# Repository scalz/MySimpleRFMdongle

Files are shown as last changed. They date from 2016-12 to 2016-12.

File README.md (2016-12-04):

# MySimpleRFMdongle
This is a 32bit ATSAM USB dongle with radio footprint for RFM69 or Lora Long range RFM95.

My main use is mini Serial Mysensors GW, and sniffer/debug tool with MYSController. etc.
Not a fancy thing, but I use it, and it didn't take lot of space on a panel when i ordered it so, why not :)

Tested with RFM69 and RFM95.
Just plug it, no usb cable!

Revision 1
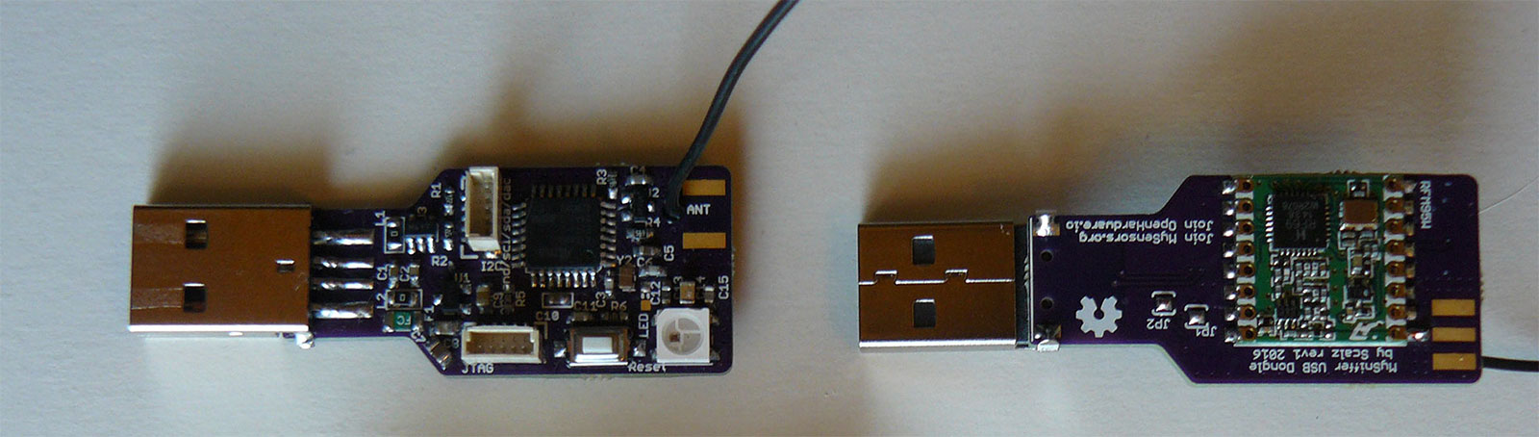
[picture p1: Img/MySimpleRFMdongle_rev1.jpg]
dongle rev1


Revision 2
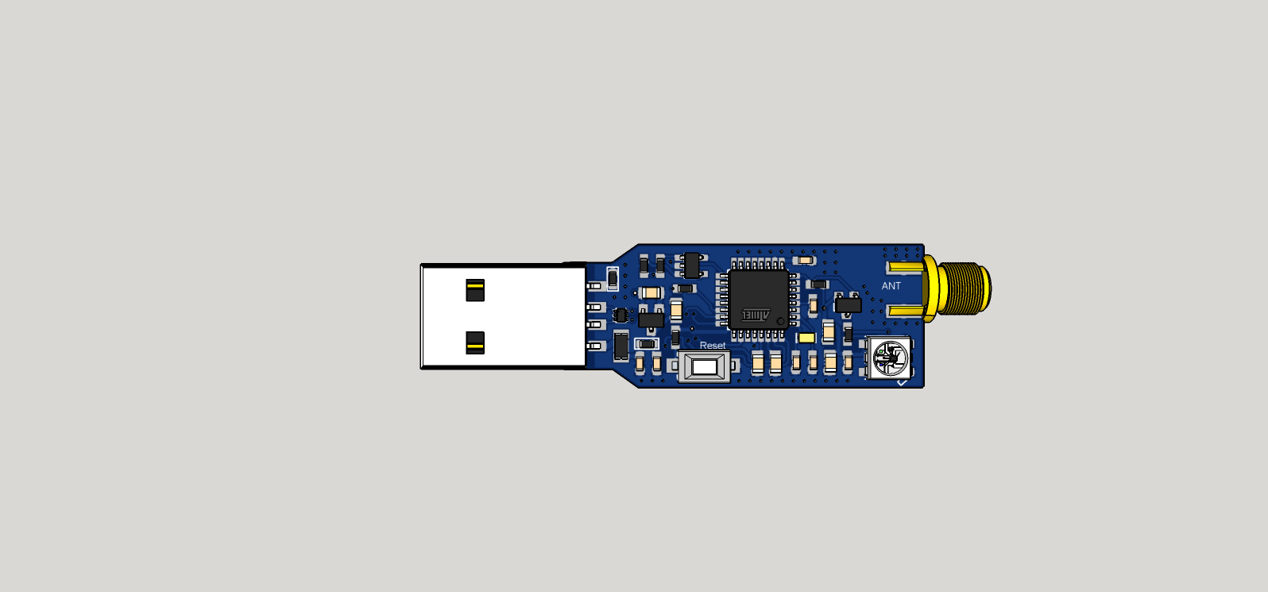
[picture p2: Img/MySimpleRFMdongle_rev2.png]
dongle rev2

Not assembled yet

###General 
------

|General spec.|  |
|---|---|---|
|Size |42.5*16.9 (mm) |
| MCU |ARM M0+ ATSAMD21E16/17/18 (same family as Arduino Zero but with 32pins) |
| Eeprom | EUI64 Eeprom |
| Authentication security | ATSHA204A chip footprint |
| Onboard led | WS2812B RGB |
| USB | USB A male connector. Sketch can be uploaded by native usb (like Arduino Zero) |
| Radio | RFM69HCW or RFM95W. SMA connector |
| Misc | Reset button |

####Onboard safety:
- Fuse + ESD protection for USB
- USB filtering

####Extension Connectors description
- Pogo pins for Cortex SWD programming
- USB for uploading sketch

####Arduino Pin description
| Arduino Pin | Description |
|---|---|---|
| 5 | Radio Interrupt Pin |
| 7 | ATSHA204A sot23 ic pin (for authentication) |
| 9 | Radio Reset Pin |
| 18 | Radio MOSI |
| 19 | Radio SCK |
| 22 | Radio MISO |
| 23 | Radio SS |
| 28 | WS2818B RGB led pin |
| 30 | SWCLK to Pogopins |
| 31 | SWDIO to Pogopins |

####Burning USB-CDC bootloader and Arduino 

I'm using Mattairtech variant board.
To find, bootloaders files and get all infos, please read : https://github.com/mattairtech/ArduinoCore-samd

Personally, I have no Atmel Ice. I use a Segger Jlink OB. It also exists cheap JTAG-SWD programmer which should work but I have not tried yet.

Simplified steps for burning bootloader with Segger Jlink OB (for more details, see links above):
1. Get a JTAG-SWD programmer. There are some cheap.
2. Download, install, and launch Atmel Studio
3. Connect your programmer to the JTAG port of the dongle
4. In Atmel Studio, go to Tools\Device Programming\ and Select your tools (the programmer), Device for MCU, Interface and apply. 
5. Try to read Id of MCU. It should be ok.
6. Then, still in the same dialog, click on Memories. Select the .hex of the bootloader you want to burn, and click Program. Then you can read, verify etc..

Then you have to install mattairtech usb driver, and boards in Arduino Ide through Boards Manager (Arduino ATSAM, and mattairtech ATSAM D21). For more details, see link above.

####Example sketch 

The example sketch is for Mysensors v2.x. This is simply the Serial GW sketch with the define for the pins. And you can add Neopixel lib.

###Overview
------

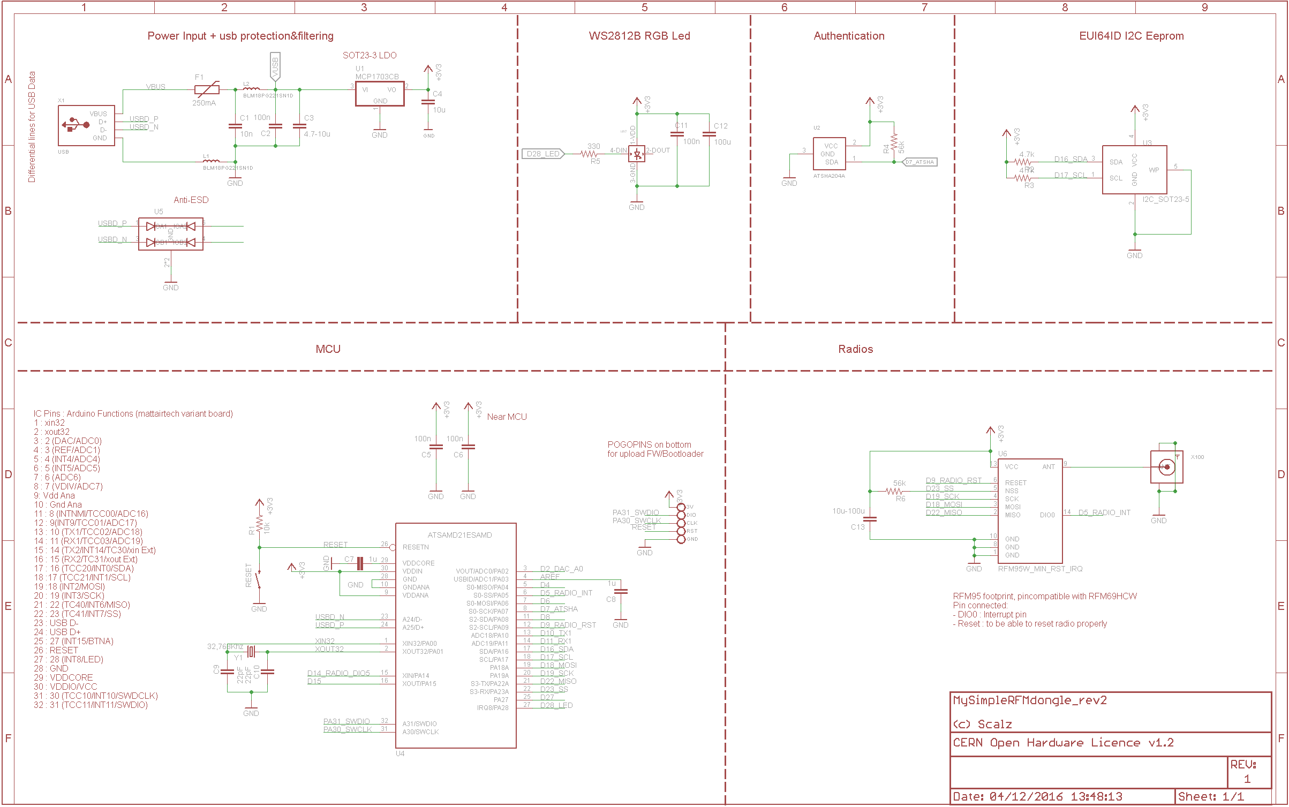
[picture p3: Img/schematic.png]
schematic


In Mysensors Serial GW mode, debugging another atsam Mysensors node. 
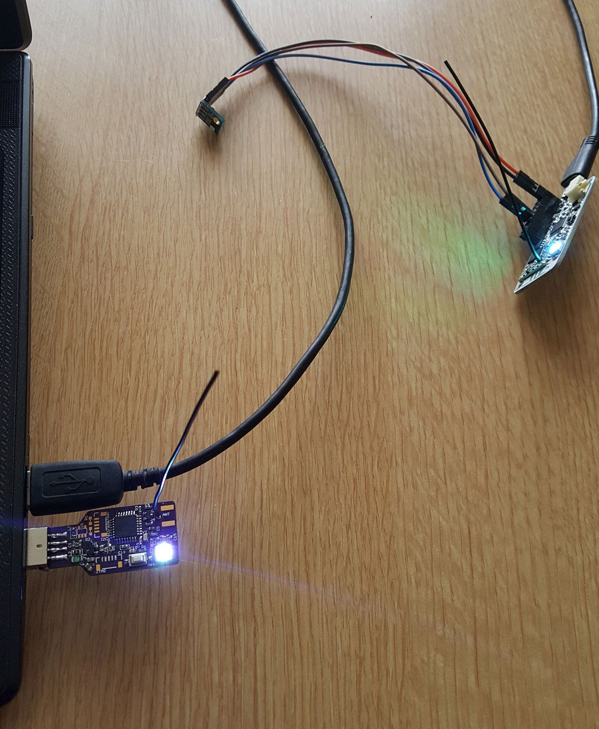
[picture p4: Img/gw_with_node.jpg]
gateway mode


###Known issues
------ 

###TODO
------
- upload STL

###Donations
------

I'm trying to make opensource projects. I do this for free and sharing spirit. I don't do ads etc..
But if you think information here is worth of some money, or want to reward me, feel free to send any amount through paypal.

  

Or you can also order pcb here :
I will earn a little percentage that will allow me to order proto pcb and share more fun design.

Or pay me a protein smoothie if you see me! oh well, a beer is ok too :)

### Contributors
------
Always special thanks to:
- Mysensors Team for its great work
- Mattairtech, Adafruit, Sparkfun, TI, Atmel etc.. for all educational infos they share

###Links, reference and license
------
- https://www.openhardware.io/view/82/My-simple-sniffer-dongle

Copyright Scalz (2016). released under the CERN Open Hardware Licence v1.2

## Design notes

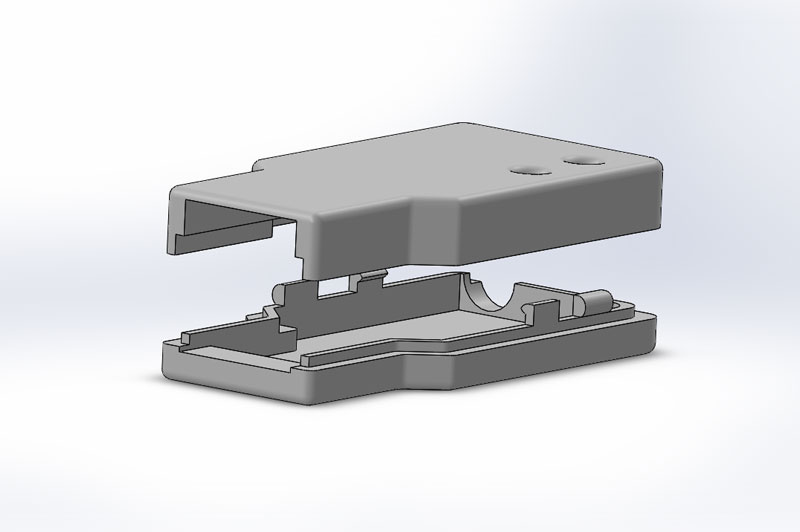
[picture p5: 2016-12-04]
Img/MySimpleRFMdongle_custombox_temp.jpg

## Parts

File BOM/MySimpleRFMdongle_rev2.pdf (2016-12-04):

Parts | Qty Value | Package | Description | MPN
C1 | 1 | 10n | 0603 | Capacitor
C2, C6, C11 3 | 100n | 0603 | Capacitor
C8 | 1 | 1u | 0603 | Capacitor
C9, C10 | 2 | 22pF | 0603 | Capacitor
C3 | 1 | 4.7u | 0805 | Capacitor
C4 | 1 | 10u | 0805 | Capacitor
C5 | 1 | 100n | 0805 | Capacitor
C7 | 1 | 1u | 0805 | Capacitor
C12 | 1 | 100u | 0805 | Capacitor
C13 | 1 | 10u | 0805 | Capacitor
LED | 1 | WS2812B | WS2812B | Neopixel
F1 | 1 | 250mA | 1206 | Resettable Fuse PTC
L1, L2 | 2 | BLM18PG221SN1D | 0603 | Ferrite bead
R1 | 1 | 10k | 0603 | Resistor
R2, R3 | 2 | 4.7k | 0603 | Resistor
R4, R6 | 2 | 56k | 0603 | Resistor
R5 | 1 | 330 | 0603 | Resistor
Y1 | 1 | 32,768Khz | CRYSTAL-SMD-2.0X1.2 | Crystal 32,768Khz 2.0X1.2mm
U1 | 1 | MCP1700, XC6206 etc.. SOT23-3 | 250 mA LDO Regulator
U2 | 1 | ATSHA204A | SOT23-3 | Signing ic
U3 | 1 | 24AA02E64T-I/OT | SOT-23-5 | EUI64 I2C Eeprom
U4 | 1 | ATSAMD21E17A-AU | TQFP32 | ATSAMD21ESAMD
U5 | 1 | TPD2E1B06DRLR | SOT-553-6
U6 | 1 | RADIO | RFM69HCW/RFM95
RESET | 1 | 1101NE | 2pins tactile switch | 1101NE tactile switch
X1 | 1 | USB | USB A Male
1 | SMA | SMA_EDGE | SMA Connector

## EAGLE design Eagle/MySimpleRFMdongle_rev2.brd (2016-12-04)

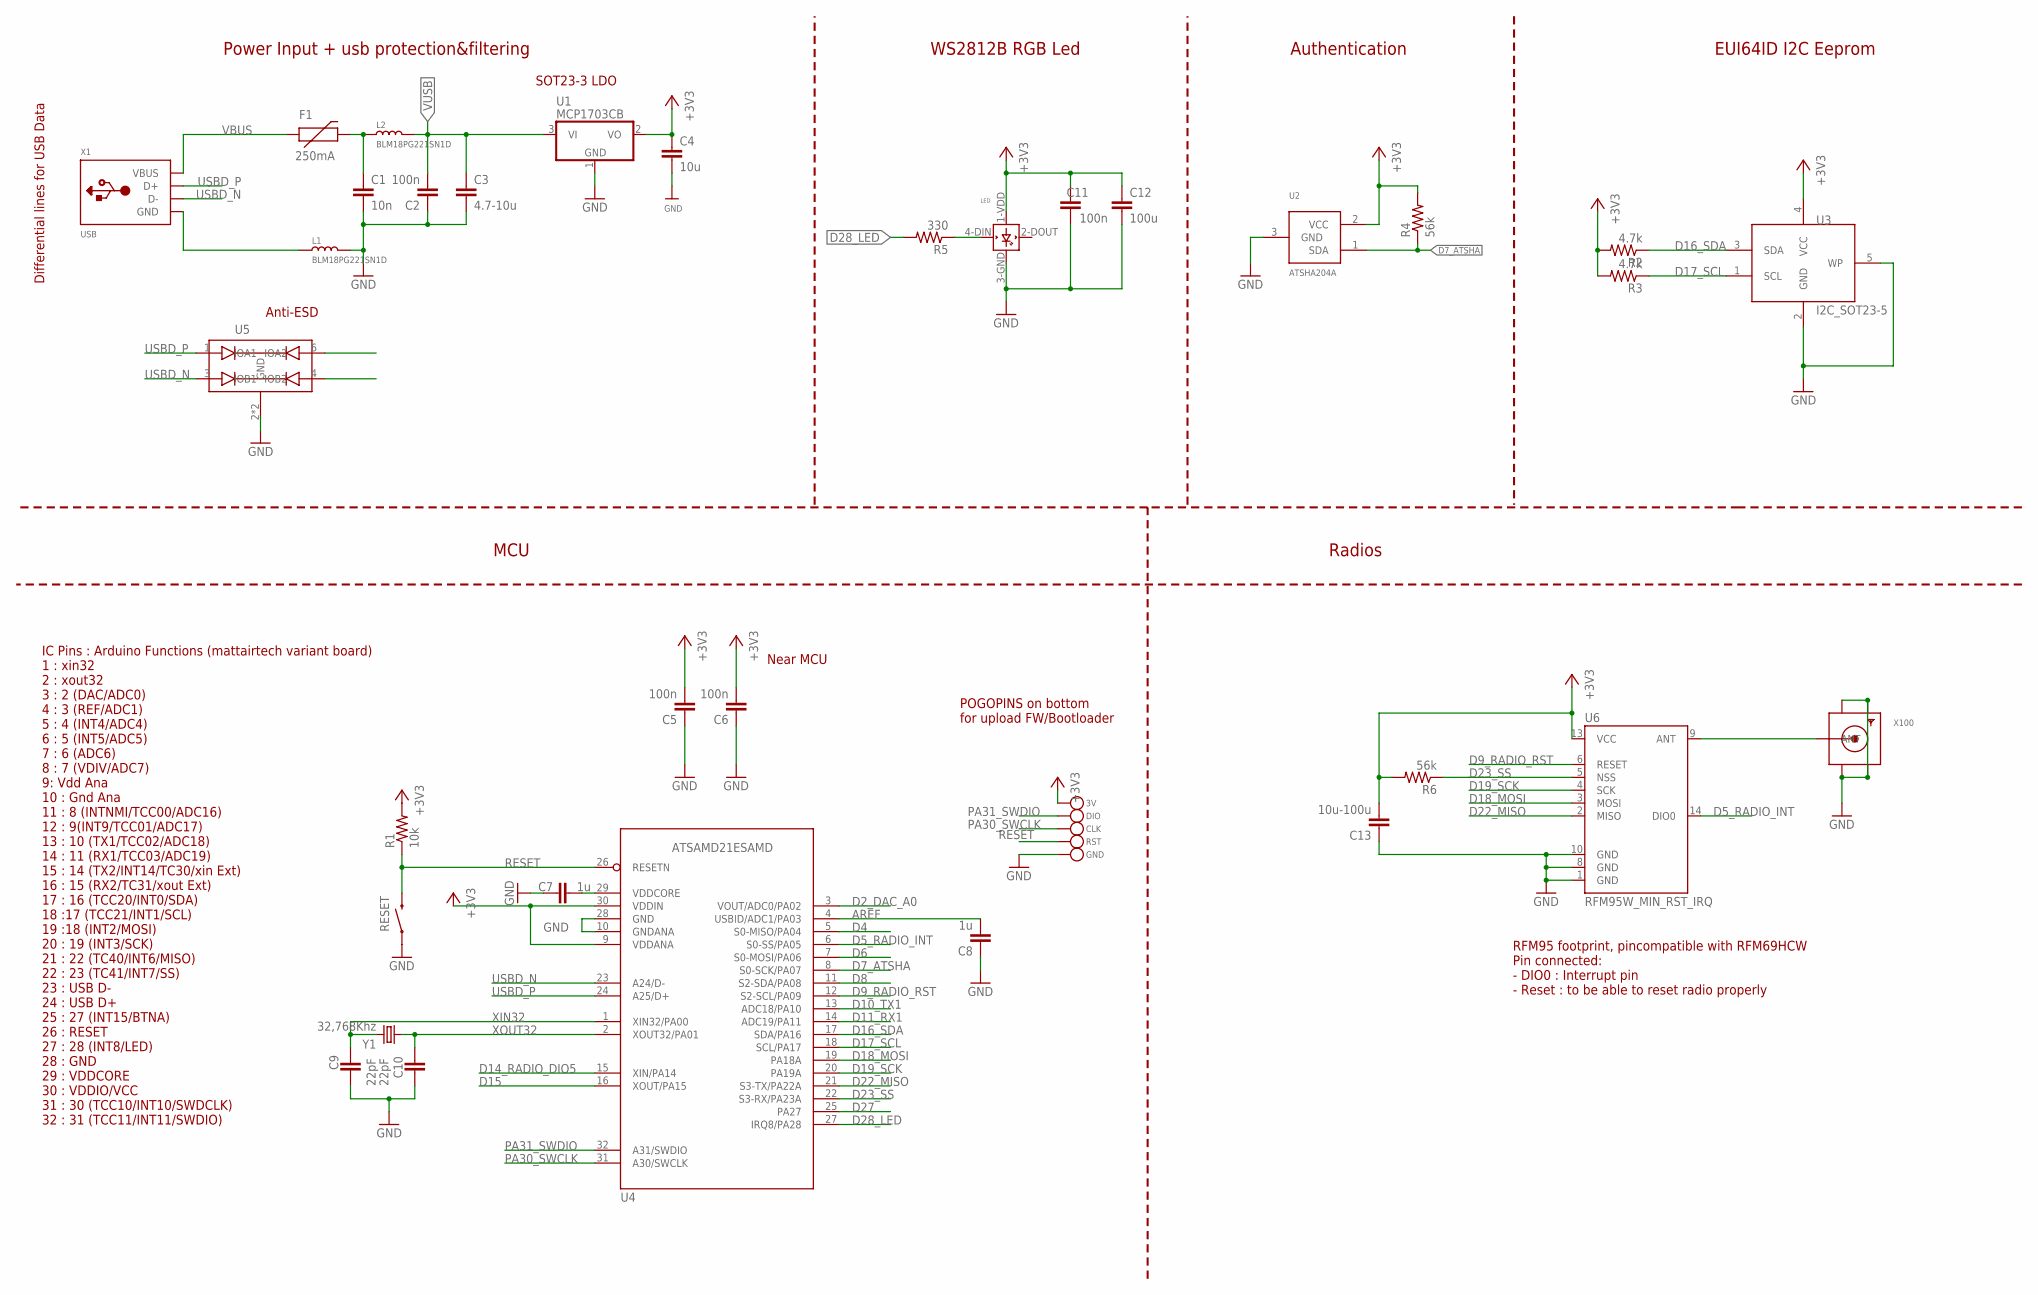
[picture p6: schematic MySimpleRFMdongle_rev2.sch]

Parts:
3V: TESTPOINTROUND1.5MM; TESTPOINT_ROUND_1.5MM
C1: 10n; 0603-CAP
C2, C6, C11: 100n; 0603-CAP
C3: 4.7-10u; 0805-CAP
C4: 10u; 0805-CAP
C5: 100n; 0805-CAP
C7: 1u; 0805-CAP
C8: 1u; 0603-CAP
C9, C10: 22pF; 0603-CAP
C12: 100u; 0805-CAP
C13: 10u-100u; 0805-CAP
CLK: TESTPOINTROUND1.5MM; TESTPOINT_ROUND_1.5MM
DIO: TESTPOINTROUND1.5MM; TESTPOINT_ROUND_1.5MM
F1: 250mA; PTC-1206
GND: TESTPOINTROUND1.5MM; TESTPOINT_ROUND_1.5MM
L1, L2: BLM18PG221SN1D; L0603
LED: WS2812B
R1: 10k; 0603-RES
R2, R3: 4.7k; 0603-RES
R4, R6: 56k; 0603-RES
R5: 330; 0603-RES
RESET: SWITCH-MOMENTARY-2-SMD-1101NE; TACTILE-SWITCH-1101NE
RST: TESTPOINTROUND1.5MM; TESTPOINT_ROUND_1.5MM
U1: MCP1703CB; SOT23
U2: ATSHA204A; SOT23
U3: I2C_SOT23-5; SOT-23-5
U4: ATSAMD21ESAMD; TQFP32-08
U5: TPD2E1B06
U6: RFM95W_MIN_RST_IRQ; RFM95W_MINI_RST_IRQ
X1: USB; MOLEX-48037-1000
X100: SMACONNECTOR_EDGE; SMA_EDGELAUNCH
Y1: 32,768Khz; CRYSTAL-SMD-2.0X1.2

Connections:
+3V3: 3V.P$1, C4.1, C5.2, C6.2, C11.2, C12.1, C13.2, LED.1-VDD (VDD), R1.2, R2.2, R3.2, R4.2, R6.2, U1.2 (VO), U2.2 (VCC), U3.4 (VCC), U4.9 (VDDANA), U4.30 (VDDIN), U6.13 (VCC)
AREF: C8.2, U4.4 (USBID/ADC1/PA03)
D2_DAC_A0: U4.3 (VOUT/ADC0/PA02)
D4: U4.5 (S0-MISO/PA04)
D5_RADIO_INT: U4.6 (S0-SS/PA05), U6.14 (DIO0)
D6: U4.7 (S0-MOSI/PA06)
D7_ATSHA: R4.1, U2.1 (SDA), U4.8 (S0-SCK/PA07)
D8: U4.11 (S2-SDA/PA08)
D9_RADIO_RST: U4.12 (S2-SCL/PA09), U6.6 (RESET)
D10_TX1: U4.13 (ADC18/PA10)
D11_RX1: U4.14 (ADC19/PA11)
D14_RADIO_DIO5: U4.15 (XIN/PA14)
D15: U4.16 (XOUT/PA15)
D16_SDA: R2.1, U3.3 (SDA), U4.17 (SDA/PA16)
D17_SCL: R3.1, U3.1 (SCL), U4.18 (SCL/PA17)
D18_MOSI: U4.19 (PA18A), U6.3 (MOSI)
D19_SCK: U4.20 (PA19A), U6.4 (SCK)
D22_MISO: U4.21 (S3-TX/PA22A), U6.2 (MISO)
D23_SS: R6.1, U4.22 (S3-RX/PA23A), U6.5 (NSS)
D27: U4.25 (PA27)
D28_LED: R5.2, U4.27 (IRQ8/PA28)
GND: C1.2, C2.1, C3.2, C4.2, C5.1, C6.1, C7.1, C8.1, C9.1, C10.1, C11.1, C12.2, C13.1, GND.P$1, L1.2, LED.3-GND (GND), RESET.P$1 (1), U1.1 (GND), U2.3 (GND), U3.2 (GND), U3.5 (WP), U4.10 (GNDANA), U4.28 (GND), U5.2 (GND), U5.5 (GND), U6.1 (GND), U6.8 (GND), U6.10 (GND), X100.GND@1 (GND4), X100.GND@2 (GND3), X100.GND@3 (GND2), X100.GND@4 (GND1)
unnamed: C1.1, F1.2, L2.1
unnamed: LED.4-DIN (DIN), R5.1
unnamed: U6.9 (ANT), X100.P (ANT)
PA30_SWCLK: CLK.P$1, U4.31 (A30/SWCLK)
PA31_SWDIO: DIO.P$1, U4.32 (A31/SWDIO)
RESET: R1.1, RESET.P$2 (2), RST.P$1, U4.26 (RESETN)
USBD_N: U4.23 (A24/D-), U5.3 (IOB1), U5.4 (IOB2), X1.2 (D-)
USBD_P: U4.24 (A25/D+), U5.1 (IOA1), U5.6 (IOA2), X1.3 (D+)
USBGND: L1.1, X1.4 (GND)
VBUS: F1.1, X1.1 (VBUS)
VDDCORE: C7.2, U4.29 (VDDCORE)
VUSB: C2.2, C3.1, L2.2, U1.3 (VI)
XIN32: C9.2, U4.1 (XIN32/PA00), Y1.2
XOUT32: C10.2, U4.2 (XOUT32/PA01), Y1.1

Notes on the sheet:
Radios
Authentication
RFM95 footprint, pincompatible with RFM69HCW Pin connected: - DIO0 : Interrupt pin - Reset : to be able to reset radio properly
Power Input + usb protection&filtering
WS2812B RGB Led
IC Pins : Arduino Functions (mattairtech variant board) 1 : xin32 2 : xout32 3 : 2 (DAC/ADC0) 4 : 3 (REF/ADC1) 5 : 4 (INT4/ADC4) 6 : 5 (INT5/ADC5) 7 : 6 (ADC6) 8 : 7 (VDIV/ADC7) 9: Vdd Ana 10 : Gnd Ana 11 : 8 (INTNMI/TCC00/ADC16) 12 : 9(INT9/TCC01/ADC17) 13 : 10 (TX1/TCC02/ADC18) 14 : 11 (RX1/TCC03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
Differential lines for USB Data
EUI64ID I2C Eeprom
SOT23-3 LDO
MCU
Anti-ESD
POGOPINS on bottom for upload FW/Bootloader
Near MCU

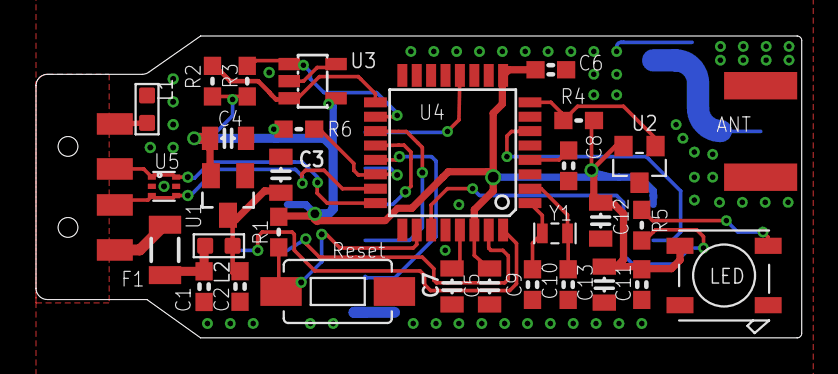
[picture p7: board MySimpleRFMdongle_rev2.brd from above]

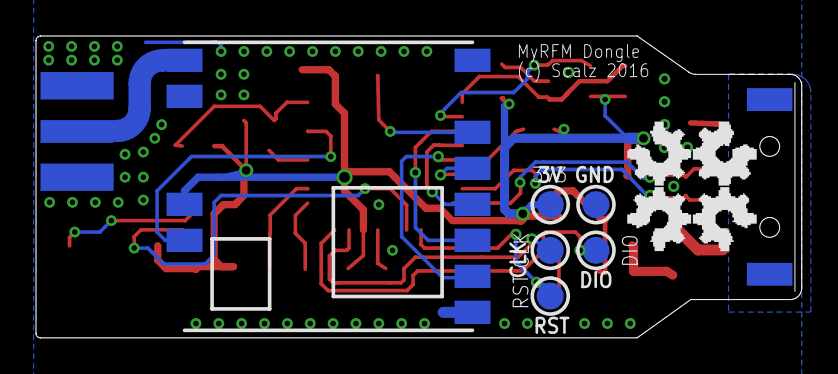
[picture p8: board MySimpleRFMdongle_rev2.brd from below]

Board: 2 copper layers, 42.5 x 16.8 mm, 39 parts (7 on the bottom side), 27 nets.

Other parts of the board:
U$2: OPENHW_SMALL_OSHPARK

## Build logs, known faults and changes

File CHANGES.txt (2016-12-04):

August 15 2016 (Scalz):
    MySimpleRFMdongle v1 
	
    Features:
		It is a simple 32bits ATSAM USB dongle with RFM95W and RFM69HCW radio support.
		- Size 42.5*16.9 (mm) 
		- MCU ARM M0+ ATSAMD21E16/17/18 (same family as Arduino Zero but with 32pins) 
		- Eeprom EUI64 Eeprom 
		- Authentication security  ATSHA204A chip footprint 
		- Onboard led  WS2812B RGB 
		- USB A male connector with fuse, antiesd, filtering
		- RFM69HCW or RFM95W. SMA connector 
		- Reset button 		
   
    Known issues:

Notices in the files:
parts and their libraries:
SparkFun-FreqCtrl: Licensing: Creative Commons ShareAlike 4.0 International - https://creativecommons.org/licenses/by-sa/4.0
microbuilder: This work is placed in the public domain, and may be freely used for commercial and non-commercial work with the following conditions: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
